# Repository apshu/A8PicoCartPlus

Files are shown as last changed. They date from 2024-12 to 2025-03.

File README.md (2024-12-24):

# A8PicoCart+ (A8PicoCart with autoboot and OLED GFX)

The aim of the A8PicoCart+ is to add autoboot feature to the excellent A8PicoCart. 

The autoboot eliminates the need to navigate trough a complex filesystem or many files (e.g. when playing zaxxon :). On power up it checks if the onboard I²C EERAM stores a valid filename. If the filename is valid, it loads the file automatically before showing the selector interface. If the last file can't be loaded (e.g. deleted) the selector GUI is shown.

If the selector UI is needed, press the Choose button on the cart during powerup.

A simple I²C OLED display is included for fun. The 128×64 monochrome display shows the loaded cart logo if the cartridge is recognized as extended format.

A new PCB was needed for the + functionality. The new PCB is 100% compatible with the original firmware, while utilizing the originally unconnected GP28 & GP29 pins for I²C.

3D printable box with the + features is available.

# A8PicoCart (UnoCart on a Raspberry Pi Pico clone)

The A8PicoCart is a multi-cart for the Atari 8-bit (XL/XE) which you can make at home with only basic soldering skills.
It is based on my earlier UnoCart design but uses a very inexpensive Raspberry Pi Pico clone (£2-3) for an easy build.

When plugged into a PC by USB it becomes a Mass Storage device allowing ROM/CAR/XEX & ATR files to be copied to the cartridge.
When plugged into an Atari these files are shown on the menu and the device will either emulate the selected cartridge type or
act as a XEX file launcher. It also has (very) limited support for ATR files allowing you to do some programming and save your
work to an ATR file.

This page contains everything you need to build the project - firmware to flash to your purple Pico clone, Kicad PCB design files to make a PCB and 3d print files for a nice case. The source code for everything is also here. There is also a manual detailing the full capabilities of the cartridge.

If you build an A8PicoCart consider donating to help fund this and my future projects:



Cased A8PicoCart in a 800xl
A8PicoCart Menu

## Quick Start

Get yourself a purple Raspberry Pi Pico clone (see [this thread](https://forums.raspberrypi.com/viewtopic.php?t=337976) for details) and order a PCB using the KiCad board files provided. You have a choice of two PCB designs - the XE design is for use uncased, with the Pico on the top surface. The XL/XE version is desgined to be mounted in a case (though can be used uncased too) with the Pico on the bottom/back surface. Once you have the Pico clone and PCB, solder the pico as pictured below, depending on your PCB version. Program the firmware onto the device by pressing BOOTSEL on the board and connecting to USB on a PC and drag the firmware (UF2 file) onto the device. It should then remount as A8-PICOCART so you can copy Atari CAR & XEX files to it. Unmount, then plug into your Atari and play! Optionally solder a reset button to reset back to the menu.

**Note**: this project does not work with the official green RPi Pico board. Although the official board has the same
number of physical pins (and will therefore fit in the PCB) - the actual pin functions are different and attempting to use
it may damage the Pico and/or your Atari. The purple clones are cheaper and have a greater number of usuable GPIO pins - 
this is required for the cartridge port emulation to work.

**Warning**: always disconnect from PC/USB before plugging into your Atari or you will damage your Atari and/or PC. This warning mainly
applies to the XE/uncased version of the PCB. The newest version of the XL/XE board makes it physically impossible to connect USB when the
cartridge is inserted in an Atari.

Purple Pico mounted on the PCBs
USB Mass Storage mode

## Inserting the cartridge

Depending on which PCB you choose the Pico clone may be mounted on the front or back of the PCB. When you insert
the cartridge in the Atari make sure the "S..A" side of the cartridge edge (NOT the "1..15" side) is facing upwards (XE) or towards you (XL).

## Purple Pico clones

The firmware is designed for the Purple Pico clones with USB C connector and 16Megs of flash and a single button (BOOTSEL).
I've received these devices with two different types of SPI flash chips - Winbond and (slower) Z-bit. The firmware has been tested with both types.

The project defines a custom board with a higher value for PICO_FLASH_SPI_CLKDIV so it supports the slower Z-bit flash.

Be aware that it's possible you might get one with another type of flash memory chip that has not been tested.

## Reset button

You can solder a push button to the cartridge to get back to the menu and avoid wear on your Atari power switch.
When you reset the cartridge the Atari will crash - just push reset on the Atari itself to get back to the menu.

The button used is a 6x6mm thru-hole tactile momentary switch. If you are going to print a case, then 9mm+ height is suitable.
When you solder the button to the PCB - make sure the lower two holes in the PCB are bridged only when the button is pressed.

It works simply by pulling the RUN pin on the pico clone to ground to reset.

## 3D print files

The STL files can be used to print a 3 part (front, back and logo) cartridge shell. The 2-tone logo is achieved by
changing the filament at the correct z-position when printing a8pico_logo.stl. You'll also need two M3 15mm screws.

Cased A8PicoCart
Cased A8PicoCart

## Changelog

* 7 Oct 2023 - Add new PCB & case design files to make it impossible to insert USB when plugged into Atari. Add support for Microcart (CAR type 52) cartridges. Updated manual.
* 29 Oct 2023 - Adds 3 new cartridge types (thanks to ascrnet)

## Credits

* Design, hardware and firmware by Robin Edwards (electrotrains at atariage)
* XEX loader and OS modifications by Jonathan Halliday (flashjazzcat at atariage)
* Altirra LLE OS used with permision from Avery Lee (phaeron at atariage)

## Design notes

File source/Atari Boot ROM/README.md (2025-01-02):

# How to compile the CART code

* Use MADs assembler [GitHub release page](https://github.com/tebe6502/Mad-Assembler/releases)
* Install Altirra 4.21 or newer [Download Page](https://www.virtualdub.org/altirra.html)
* Use VSCode with [MADS plugin](https://marketplace.visualstudio.com/items?itemName=mirao.mads) and [Atasm Altirra Bridge](https://marketplace.visualstudio.com/items?itemName=cerebus.atasm-altirra-bridge)
* Install [Python](https://www.python.org/) 3.12 or newer

The current setup is available for Windows only. Linux porting should be fairly easy.

Set the Altirra executeable path [-> VSCODE setting](vscode://settings/atasm-altirra-bridge.emulator.altirra.path) to bridge.bat

Add the Altirra bridge specific settings to atasm-build.json
```json
	"_7": "Altirra command line parameters for developing a cartridge",
	"bridgeParams": {
		"altirraExecutable": "D:\\Games\\Altirra\\Altirra64.exe",
		"bptList": ["A001","read_joystick.done"],
		"altirraDebugArgumentTemplate": "/cartmapper 1 /cart {' '.join(args[1:])} /debugcmd:\\\".sourcemode on\\\" {' '.join(map('/debugcmd:\"bp {}\"'.format, getattr(config.bridgeParams, 'bptList', [])))}",
		"altirraArgumentTemplate": "/cartmapper 1 /cart {' '.join(args[1:])}"
	}
```
> [!IMPORTANT]
> Adjust the "_altirraExecutable_" to match the full path and executeable of your selected Altirra

> [!NOTE]
> The example above is for developing cartridges

> [!TIP]
> "_bptList_" section may contain Address or symbol name to set breakpoints on load.

# Convert the compiled code to _.h_

When the Cart code is finished, run the _convert.bat_, review the generated _rom.h_ and copy the _rom.h_ to the Pico source folder. 

Recompile the Pico Code and the new CART is incorporated as default.

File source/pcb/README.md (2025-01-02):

# XL/XE version PCB (which fits the 3d printed case design)

* KiCad Project wirh 3D models 
* KiCad Version: 8.0.3, release build
* A zip file of the gerbers (JLCPCB specification).
* Updated version with EERAM and OLED display 
 
## PCB specifications:
* 70.04 × 53.8 mm
* 2 layers
* 1.6 mm thickness
* Minimum drill 0.3 mm
* Hard gold fingers with bevelled edge will make your PCB last longer, but at a much higher cost.

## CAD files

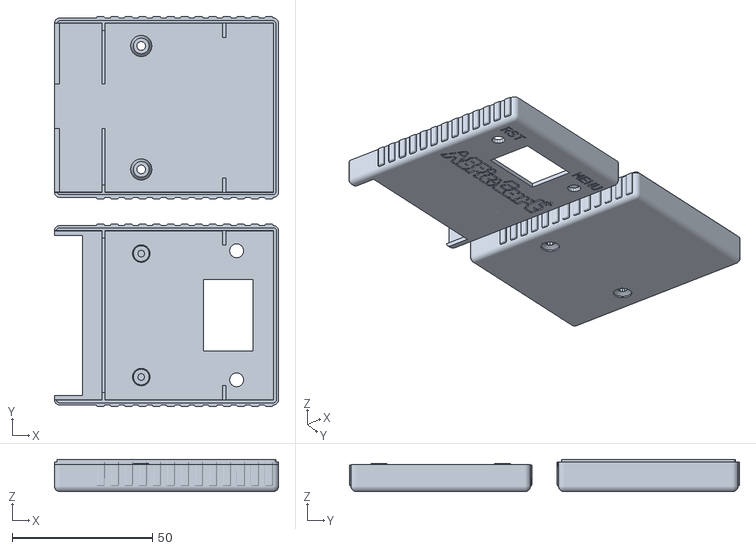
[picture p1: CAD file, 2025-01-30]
release/a8picoplus_shell.stl
80.0 x 139.0 x 11.5

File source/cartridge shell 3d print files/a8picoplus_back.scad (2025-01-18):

/* A8PicoCart shell
   (c) R.Edwards 2023
*/

include <a8picoplus_dimensions.scad>
use <cube_round.scad>

module back_outside()
{
    cube_round([cart_length, cart_width, cartb_height-rim_height], corner_r,
        fn=corner_fn, round_top=false);

    // rim
    translate([sides_thickness/2+rim_clearance, sides_thickness/2+rim_clearance, 0])
        cube_round([cart_length-sides_thickness-2*rim_clearance, cart_width-
            2*sides_thickness/2 - 2*rim_clearance,
            cartb_height], corner_r-sides_thickness/2,
            fn=corner_fn, round_top=false);

    // ridges
    for (i = [15: 5: cart_length-5])
        translate([i, -ridge_width, corner_r])
            cube_round([3, cart_width + 2*ridge_width,
                cartb_height-rim_height-corner_r],r=ridge_width,fn=corner_fn,round_top=false);

}


module back_inside()
{
    //FIXME  name the "4"
    // upper part, whole lenght
    translate([-1, sides_thickness, front_thickness+4])
        cube_round([cart_length-sides_thickness+1,
            cart_width-sides_thickness*2,
            cartb_height-front_thickness],
            r = corner_r-sides_thickness, fn = corner_fn,
            round_top=false);

    //inside part without the wall on the header end
    translate([sides_thickness, sides_thickness, front_thickness])
        cube_round([cart_length-sides_thickness*2,
            cart_width-sides_thickness*2,
            cartb_height-front_thickness],
            r = corner_r-sides_thickness, fn = corner_fn,
            round_top=false);
    // cutout USB slot
    translate([-1, (cart_width-16)/2+0.5, front_thickness])    // pico is 0.5 mm off center
        cube([40+1, 16, cartb_height]);


}

module screw_hole()
{
    translate([0, 0, -1])
        cylinder(h = supportb_height - 1.2 + 2, r = 1.6,  $fs = 1);
    translate([0, 0, -1])
        cylinder(h = 1.6, r = 3.5, $fs = 1);
    translate([0, 0, 0.6])
        cylinder(h = front_thickness-0.6, r1 = 3.5, r2 = 1.8,  $fs = 1);
}

module pcb_support()
{
        difference() {
            translate([17, sides_thickness, sides_thickness/2])
                cube([support_thickness, cart_width-sides_thickness*2,
cartb_height-sides_thickness/2]);
            translate([17-1, (cart_width-55)/2, supportb_height])
                cube([support_thickness+2, 55, cartb_height-supportb_height+1]);

               // cutout USB slot
            translate([17-1, (cart_width-16)/2+0.5, front_thickness])    // pico is 0.5 mm off center
                 cube([support_thickness+2, 16, cartb_height]);
        }

        translate([60, sides_thickness, sides_thickness])
            cube([support_thickness, 7-sides_thickness,
                    supportb_height-sides_thickness]);
        translate([60, cart_width-7, sides_thickness])
            cube([support_thickness, 7-sides_thickness/2,
supportb_height-sides_thickness]);



}

module back() {

difference() {
    union() {
        difference() {
            // main shell
            back_outside();
                        // make hollow
            back_inside();
       } 
   
        // pcb supports
        pcb_support();

        // screw stud
        translate([31, (cart_width-screw_sep)/2, 0])
                cylinder(h = supportb_height - 1.2, r1 = 4, r2 = 2.8,  $fs = 1);
        translate([31, cart_width-(cart_width-screw_sep)/2, 0])
                cylinder(h = supportb_height - 1.2, r1 = 4, r2 = 2.8,  $fs = 1);
    }


    // screw holes
    translate([31, (cart_width-screw_sep)/2, 0])
        screw_hole();

    translate([31, cart_width-(cart_width-screw_sep)/2, 0])
        screw_hole();

}

}


back();

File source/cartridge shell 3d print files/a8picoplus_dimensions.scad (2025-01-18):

/* A8PicoCart shell
   (c) R.Edwards 2023
*/

/*common ones */
/* Dimensions */
ridge_width = 0.5;
cart_length=80;
cart_width=65 - (ridge_width*2);
screw_sep = 44;
front_thickness = 1.6;
sides_thickness = 1.8;
support_thickness = 1.2 - 0.05;
rim_height=1;
rim_clearance=0.1;

corner_r=2;
corner_fn=32;

/* back */
/* height of the back side part */
cartb_height=11.5;
supportb_height = 10.5;

/* front */

/* Features */
menu_button = true;
OLED_mount = true;
show_logo = true;

/*height of the front side part */
cartf_height=9.6;
supportf_height = 7.6;
port_cut_height=10;
logo_width = 14.5;
logo_height = 58;
logo_image = "a8picoplus_logo.png";
image_size=[363,88];

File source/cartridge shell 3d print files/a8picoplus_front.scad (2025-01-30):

/* A8PicoCart shell
   (c) R.Edwards 2023
   A8PicCart+ shell
   APShu 2025
*/

include <a8picoplus_dimensions.scad>
include <cube_round.scad>

module front_outside()
{
    // main shell
    cube_round([cart_length, cart_width, cartf_height],r=corner_r,fn=corner_fn, round_top=false);

    // ridges
    for (i = [15: 5: cart_length-5])
                translate([i, -ridge_width, corner_r])
                    cube_round([3, cart_width + 2*ridge_width,
cartb_height-rim_height-1-corner_r],r=ridge_width,round_top=false);


}

module front_inside() {
    // rims
    translate([sides_thickness/2-rim_clearance,cart_width -
        sides_thickness/2+rim_clearance, cartf_height-rim_height +
        rim_height+corner_r])
        rotate([180,0,0])
        cube_round([cart_length-sides_thickness+2*rim_clearance,
            cart_width-sides_thickness+2*rim_clearance,
            rim_height+corner_r],
            r=corner_r-sides_thickness/2,fn=corner_fn,round_top=false);

    // make hollow
    translate([-1, sides_thickness, front_thickness])
        cube_round([cart_length-sides_thickness+1,
            cart_width-sides_thickness*2,
            cartf_height-front_thickness+1],
            r=corner_r-sides_thickness,fn=corner_fn,round_top=false);

    // cutout cart port
    translate([-1, (cart_width-57)/2, -1])
        cube([port_cut_height+1, 57, cartf_height+2]);

    // Reset button
    translate([cart_length-15, 9, -1])
        cylinder(h = front_thickness+2, r1 = 2.5, r2 = 2.5,  $fs = 1); 

    // Menu button
    if (menu_button) {
        translate([cart_length-15, cart_width-9, -1])
            cylinder(h = front_thickness+2, r1 = 2.5, r2 = 2.5,  $fs = 1); 
    }
    
    // OLED mount
    if (OLED_mount) {
        translate([cart_length-18, cart_width/2, 0])
            cube([17.6, 25.6,front_thickness*4], center=true); 
    }
}

module front_screw_mount()
{
    difference() {
        cylinder(h = supportf_height + 2.5, r1 = 3.2, r2 = 2.8,  $fs = 1);
        translate([0,0,-1])
            cylinder(h = supportf_height + 2.5+2, r1 = 1.25, r2 = 1.25,  $fs = 1);
    }

}

module front_wo_logo()
{
    difference() {
        front_outside();
        front_inside();
    }    
    // pcb supports
    difference() {
        //FIXME 17 as variable
        translate([17, sides_thickness/2, sides_thickness/2])
            cube([support_thickness, cart_width-sides_thickness,
cartf_height-rim_height-sides_thickness/2]);
        translate([17-1, (cart_width-55)/2, supportf_height])
            cube([support_thickness+2, 55, cartf_height-supportf_height]);
    }

    translate([60, sides_thickness/2, sides_thickness/2])
        cube([support_thickness, 7-sides_thickness/2,
supportf_height-sides_thickness/2]);
    translate([60, cart_width-7, sides_thickness/2])
        cube([support_thickness, 7-sides_thickness/2,
supportf_height-sides_thickness/2]);

    // screw holes
    translate([31, (cart_width-screw_sep)/2, 0])
        front_screw_mount();
    translate([31, cart_width-(cart_width-screw_sep)/2, 0])
        front_screw_mount();
}

module front_logo_hole() {

    difference() {
        front_wo_logo();
        // logo space
        translate([cart_length-logo_height-2, cart_width-logo_width-3.5, -1])
            cube([logo_height, logo_width, 1+1]);
    }
}

module logo()
{
    echo("rendering logo");
    rect_line_width=0.5;
    logo_depth=0.6;
    scl = (logo_height-rect_line_width)/image_size[0];

    /* logo text */
    intersection(){
        cube([logo_height, logo_width, logo_depth+1]);
    //FIXME why the "-1" to shift the logo lower and to the left side??
        translate([logo_height/2+rect_line_width-0.5,logo_width/2+rect_line_width -1 ,100/2])
            scale([scl,scl,1])
            mirror([0,1,0])
            surface(file = logo_image, center = true, invert = true);
    }
}

module reset_label()
{
    font = "Liberation Mono:style=Medium";
    rpi_logo_scale = 0.22;
    rst_height = 1.6;

    rotate([0,0,90])
        mirror([0,1,0])
            linear_extrude(height = rst_height) {
                translate([-38,0]) 
                    text(text = str("RST"), font = font, size = 30);
            }
}

module menu_label()
{
    font = "Liberation Mono:style=Medium";
    rpi_logo_scale = 0.22;
    rst_height = 1.6;

    rotate([0,0,90])
        mirror([0,1,0])
            linear_extrude(height = rst_height) {
                translate([-55,0]) 
                    text(text = str("MENU"), font = font, size = 30);
            }
}

module front() {

    difference() {
        front_wo_logo();
        //logo rectangle
        if (show_logo) {
            if (OLED_mount) {
                translate([cart_length-28,(cart_width-logo_height)/ 2, -1]) rotate([0, 0, 90]) logo();
            } else {
                translate([cart_length-logo_height-3, (cart_width-logo_width)/ 2, -1]) logo();
            }
        }
        translate([cart_length-15+5, 9, -1]) scale([0.15,0.15,1]) reset_label();
        if (menu_button) {
            translate([cart_length-15+5, cart_width-9, -1]) scale([0.15,0.15,1]) menu_label();
        }
    }
}

front();

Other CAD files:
source/cartridge shell 3d print files/a8picoplus_shell.scad
source/cartridge shell 3d print files/cube_round.scad

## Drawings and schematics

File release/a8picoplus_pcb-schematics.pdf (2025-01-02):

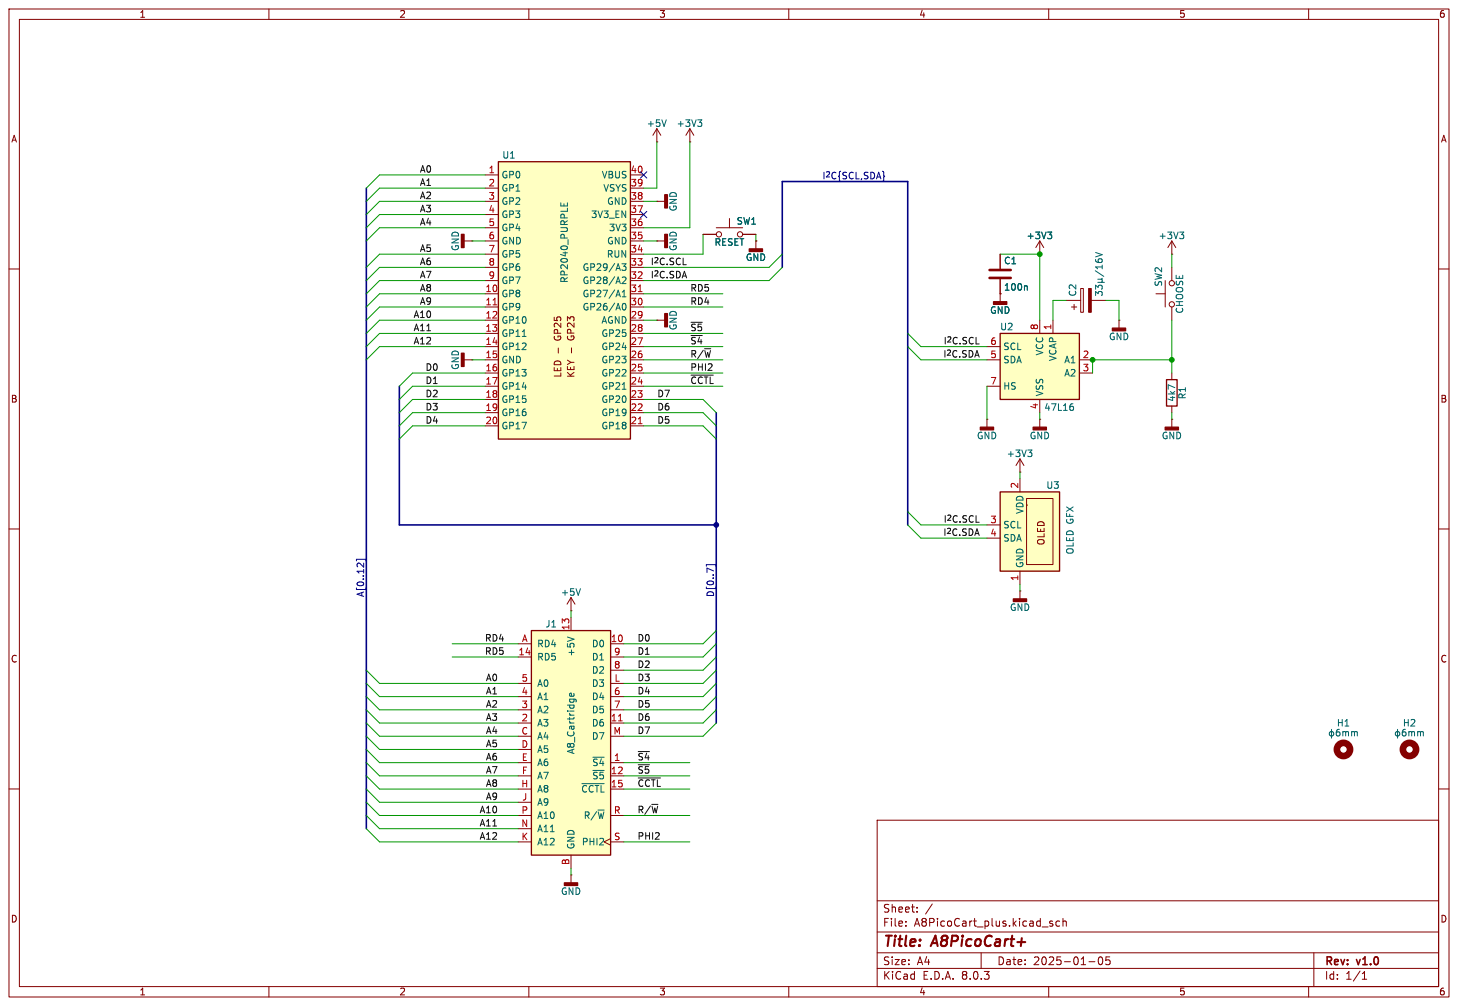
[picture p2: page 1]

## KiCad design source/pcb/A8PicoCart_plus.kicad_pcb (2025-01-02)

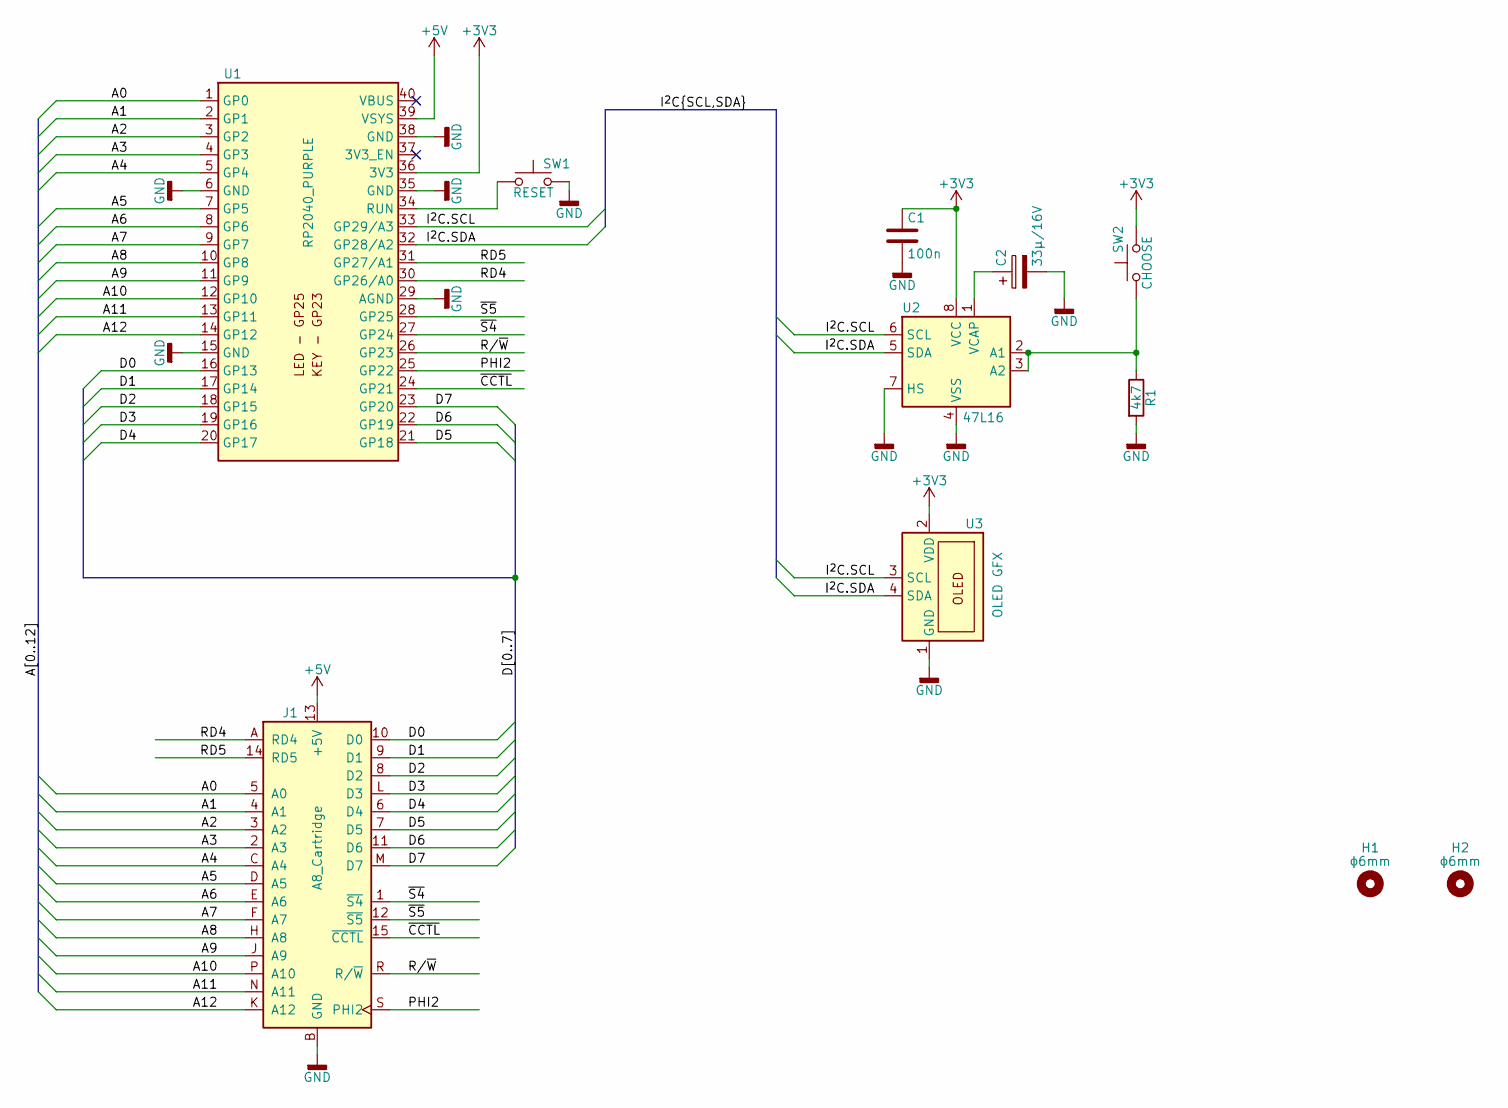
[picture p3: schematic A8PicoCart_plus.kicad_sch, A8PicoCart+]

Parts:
C1: 100n; C_0805_2012Metric_Pad1.18x1.45mm_HandSolder
C2: 33µ/16V; CP_Radial_D4.0mm_P2.00mm
H1, H2: ϕ6mm; MountingHole_6mm
J1: A8_Cartridge; Cartridge_A8
R1: 4k7; R_0805_2012Metric_Pad1.20x1.40mm_HandSolder
SW1: RESET; SW_PUSH_6mm_H8mm
SW2: CHOOSE; SW_PUSH_6mm_H8mm
U1: RP2040_PURPLE; RP2040_purple_nodbg
U2: 47L16; SOIC-8_3.9x4.9mm_P1.27mm
U3: OLED GFX; JST_XH_B4B-XH-A_1x04_P2.50mm_Vertical

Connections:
+3V3: C1.1, SW2.2, U1.36 (3V3), U2.8 (VCC), U3.2 (VDD)
+5V: J1.13 (+5V), U1.39 (VSYS)
/A0: J1.5 (A0), U1.1 (GP0)
/A1: J1.4 (A1), U1.2 (GP1)
/A2: J1.3 (A2), U1.3 (GP2)
/A3: J1.2 (A3), U1.4 (GP3)
/A4: J1.C (A4), U1.5 (GP4)
/A5: J1.D (A5), U1.7 (GP5)
/A6: J1.E (A6), U1.8 (GP6)
/A7: J1.F (A7), U1.9 (GP7)
/A8: J1.H (A8), U1.10 (GP8)
/A9: J1.J (A9), U1.11 (GP9)
/A10: J1.P (A10), U1.12 (GP10)
/A11: J1.N (A11), U1.13 (GP11)
/A12: J1.K (A12), U1.14 (GP12)
/D0: J1.10 (D0), U1.16 (GP13)
/D1: J1.9 (D1), U1.17 (GP14)
/D2: J1.8 (D2), U1.18 (GP15)
/D3: J1.L (D3), U1.19 (GP16)
/D4: J1.6 (D4), U1.20 (GP17)
/D5: J1.7 (D5), U1.21 (GP18)
/D6: J1.11 (D6), U1.22 (GP19)
/D7: J1.M (D7), U1.23 (GP20)
/I^{2}C.SCL: U1.33 (GP29/A3), U2.6 (SCL), U3.3 (SCL)
/I^{2}C.SDA: U1.32 (GP28/A2), U2.5 (SDA), U3.4 (SDA)
/PHI2: J1.S (PHI2), U1.25 (GP22)
/RD4: J1.A (RD4), U1.30 (GP26/A0)
/RD5: J1.14 (RD5), U1.31 (GP27/A1)
/R/~W: J1.R (R/~W), U1.26 (GP23)
/~CCTL: J1.15 (~CCTL), U1.24 (GP21)
/~S4: J1.1 (~S4), U1.27 (GP24)
/~S5: J1.12 (~S5), U1.28 (GP25)
GND: C1.2, C2.2, J1.B (GND), R1.2, SW1.2, U1.6 (GND), U1.15 (GND), U1.29 (AGND), U1.35 (GND), U1.38 (GND), U2.4 (VSS), U2.7 (HS), U3.1 (GND)
unnamed: SW1.1, U1.34 (RUN)
unnamed: R1.1, SW2.1, U2.2 (A1), U2.3 (A2)
unnamed: C2.1, U2.1 (VCAP)

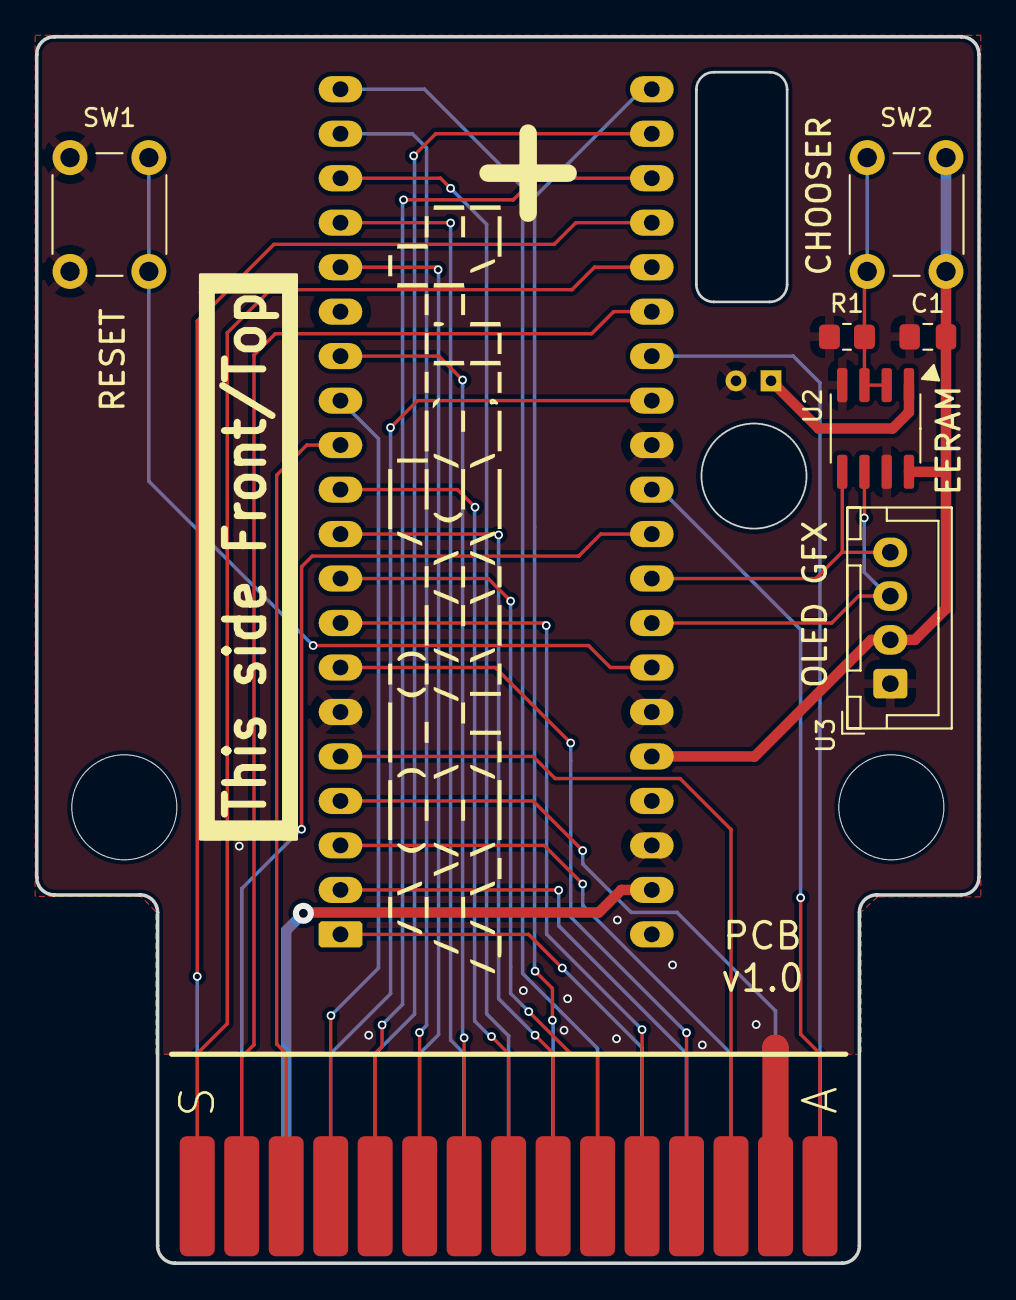
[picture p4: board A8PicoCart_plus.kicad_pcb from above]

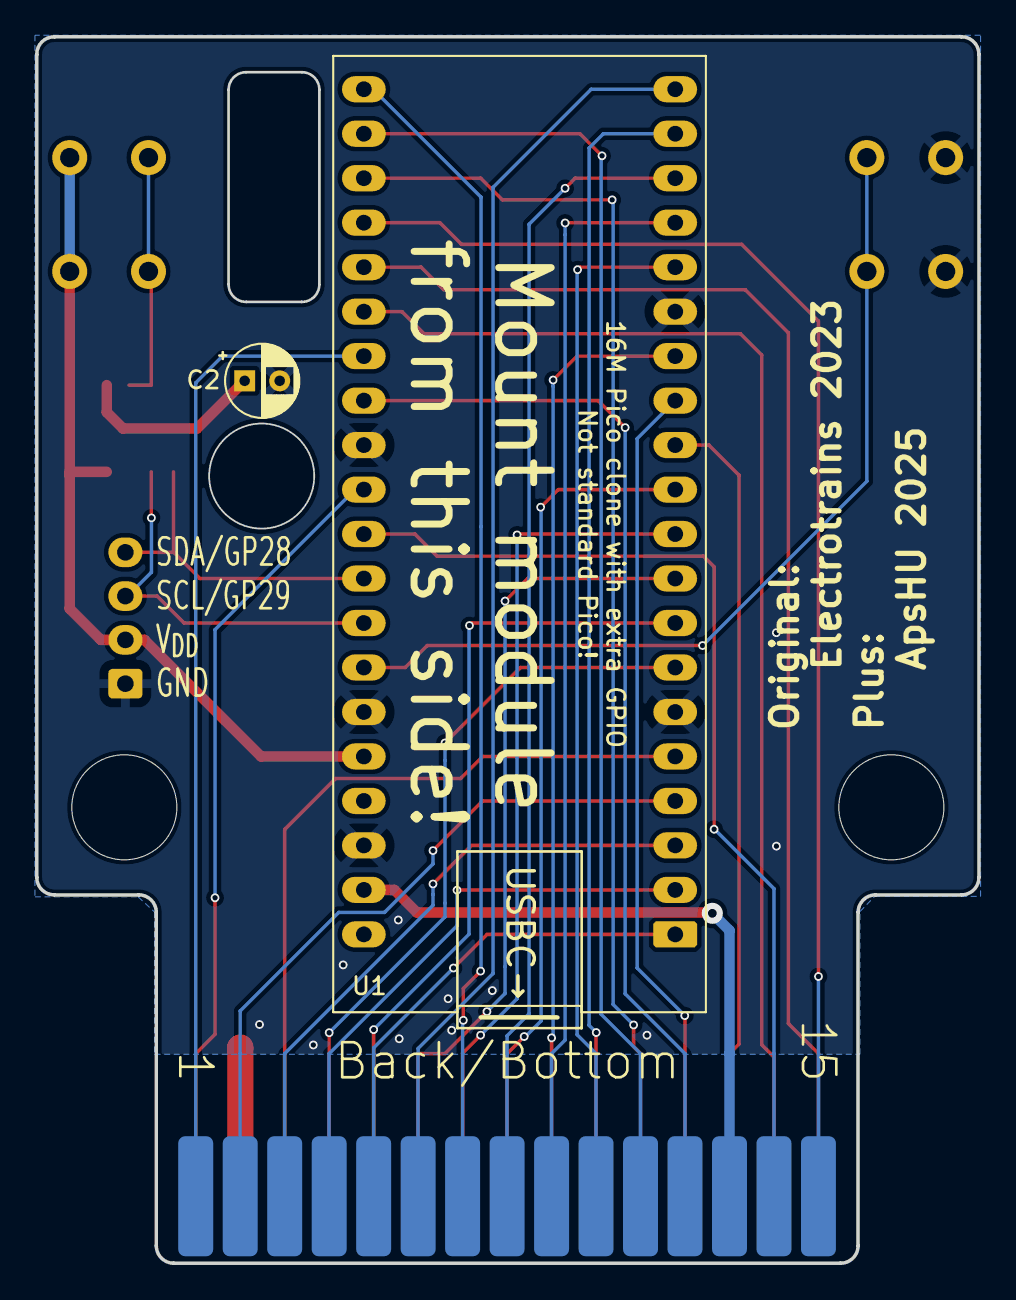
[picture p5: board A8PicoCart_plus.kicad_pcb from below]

Board: 2 copper layers, 53.8 x 70.0 mm, 11 parts (3 on the bottom side), 36 nets.

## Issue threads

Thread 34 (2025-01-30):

Case OLED cutout too small

apshu, 2025-01-30:
Make 1mm larger

Closed 2025-01-30.

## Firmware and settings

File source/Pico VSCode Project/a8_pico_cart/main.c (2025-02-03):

/**
 *    _   ___ ___ _       ___          _   
 *   /_\ ( _ ) _ (_)__ _ / __|__ _ _ _| |_ 
 *  / _ \/ _ \  _/ / _/_\ (__/ _` | '_|  _|
 * /_/ \_\___/_| |_\__\_/\___\__,_|_|  \__|
 *                                         
 * 
 * Atari 8-bit cartridge for Raspberry Pi Pico (16MB clone with all GPIO)
 *
 * Robin Edwards 2023
 *
 * Needs to be a release NOT debug build for the cartridge emulation to work
 * 
 * Edit myboard.h depending on the type of flash memory on the pico clone
 */

#include <stdlib.h>
#include <stdio.h>
#include <string.h>

#include "pico/stdlib.h"
#include "pico/time.h"
#include "tusb.h"

#include "atari_cart.h"
#include "fatfs_disk.h"

#include "hardware/i2c.h"
#include "ssd1306.h"

void cdc_task(void);

int main(void)
{
    // check to see if we are plugged into Atari 8-bit
    // by checking for high on PHI2 gpio for 100ms
    gpio_init(ATARI_PHI2_PIN);
    gpio_set_dir(ATARI_PHI2_PIN, GPIO_IN);

    // Configuring the I2C host mode
    i2c_init(i2c_default, DEFAULT_I2C_CLK_SPEED);
    gpio_set_function(PICO_DEFAULT_I2C_SCL_PIN, GPIO_FUNC_I2C);
    gpio_set_function(PICO_DEFAULT_I2C_SDA_PIN, GPIO_FUNC_I2C);
    gpio_pull_up(PICO_DEFAULT_I2C_SCL_PIN);
    gpio_pull_up(PICO_DEFAULT_I2C_SDA_PIN);

    while (to_ms_since_boot(get_absolute_time()) < 100)
    {
      if (gpio_get(ATARI_PHI2_PIN))
        atari_cart_main();
    }

  // we are presumably powered from USB
  // enter USB mass storage mode

  stdio_init_all();   // for serial output, via printf()
  printf("Start up\n");  
  
  if (SSD1306_init()) {     // Init GFX display
    // Initialize render area for entire frame (SSD1306_WIDTH pixels by SSD1306_NUM_PAGES pages)
    uint8_t lcd_buf[SSD1306_BUF_LEN];
    // zero the entire display buffer
    memset(lcd_buf, 0, SSD1306_BUF_LEN);
    GFX_render_area_t frame_area = {
      start_col: 0,
      end_col : SSD1306_WIDTH - 1,
      start_page : 0,
      end_page : SSD1306_NUM_PAGES - 1
    };

    GFX_calc_render_area_buflen(&frame_area);
    // Render the text
    GFX_WriteString(lcd_buf, 15, (SSD1306_HEIGHT>>1) - 10, "Drag and drop");
    GFX_WriteString(lcd_buf, 20, (SSD1306_HEIGHT>>1) + 10, "Atari files");
    // Show the buffer on screen
    SSD1306_render(lcd_buf, &frame_area);
  }
  
  // init device stack on configured roothub port
  tud_init(BOARD_TUD_RHPORT);

  while (1)
  {
    tud_task(); // tinyusb device task

    cdc_task();
  }

  return 0;
}

//--------------------------------------------------------------------+
// Device callbacks
//--------------------------------------------------------------------+

// Invoked when device is mounted
void tud_mount_cb(void)
{
  printf("Device mounted\n"); 
  if (!mount_fatfs_disk()) {
    // Issues with FS, complete FS format
    create_fatfs_disk();
    // Reset EERAM regardless of NOAUTOBOOT button
    reset_eeram(true); 
  }
}

// Invoked when device is unmounted
void tud_umount_cb(void)
{
  printf("Device unmounted\n");  
}

// Invoked when usb bus is suspended
// remote_wakeup_en : if host allow us  to perform remote wakeup
// Within 7ms, device must draw an average of current less than 2.5 mA from bus
void tud_suspend_cb(bool remote_wakeup_en)
{
  (void) remote_wakeup_en;
//  blink_interval_ms = BLINK_SUSPENDED;
}

// Invoked when usb bus is resumed
void tud_resume_cb(void)
{
//  blink_interval_ms = BLINK_MOUNTED;
}


//--------------------------------------------------------------------+
// USB CDC
//--------------------------------------------------------------------+
void cdc_task(void)
{
  // connected() check for DTR bit
  // Most but not all terminal client set this when making connection
  // if ( tud_cdc_connected() )
  {
    // connected and there are data available
    if ( tud_cdc_available() )
    {
      // read data
      char buf[64];
      uint32_t count = tud_cdc_read(buf, sizeof(buf));
      (void) count;

      // Echo back
      // Note: Skip echo by commenting out write() and write_flush()
      // for throughput test e.g
      //    $ dd if=/dev/zero of=/dev/ttyACM0 count=10000
      tud_cdc_write(buf, count);
      tud_cdc_write_flush();
    }
  }
}

// Invoked when cdc when line state changed e.g connected/disconnected
void tud_cdc_line_state_cb(uint8_t itf, bool dtr, bool rts)
{
  (void) itf;
  (void) rts;

  // TODO set some indicator
  if ( dtr )
  {
    // Terminal connected
  }else
  {
    // Terminal disconnected
  }
}

// Invoked when CDC interface received data from host
void tud_cdc_rx_cb(uint8_t itf)
{
  (void) itf;
}

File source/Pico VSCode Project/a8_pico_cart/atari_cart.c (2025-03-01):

/**
 *    _   ___ ___ _       ___          _   
 *   /_\ ( _ ) _ (_)__ _ / __|__ _ _ _| |_ 
 *  / _ \/ _ \  _/ / _/_\ (__/ _` | '_|  _|
 * /_/ \_\___/_| |_\__\_/\___\__,_|_|  \__|
 *                                         
 * 
 * Atari 8-bit cartridge for Raspberry Pi Pico
 *
 * Robin Edwards 2023
 *
 * Needs to be a release NOT debug build for the cartridge emulation to work
 * 
 * Changes from UnoCart:
 * - Attempts to get S4/S5, RD4/RD5 MMU behaviour correct on 400/800
 *   https://forums.atariage.com/topic/241888-ultimate-cart-sd-multicart-technical-thread/page/10/#comment-4266797
 * - Adds 4k carts (CAR type 58)
 * - Adds Turbsoft carts (CAR types 50,51)
 * - Adds ATRAX 128k carts (CAR type 17)
 * - Adds Microcalc/Utracart (CAR type 52)
 * - Adds Standard 2k cars (CAR type 57)
 * - Adds Phoenix 8k cars (CAR type 39)
 * - Adds Blizzard 4k cars (CAR type 46)
 * - Adds Dawliah 32k cars (CAR type 69)
 * - Adds Telelink II 8k car (CAR type 78)
 * - Adds Turbo 2000 8k cars (CAR type 253 exclusive emulation)
 * - Adds JNSoft 16k cars (CAR type 252 exclusive emulation)
 */

#include <string.h>
#include <stdlib.h>

#include "pico/stdlib.h"
#include "hardware/sync.h"
#include "hardware/clocks.h"
#include "hardware/i2c.h"

#include "atari_cart.h"

#include "ff.h"
#include "fatfs_disk.h"

#include "eeram_i2c.h"
#include "ssd1306.h"

#if !(defined(PICO_DEFAULT_I2C_SCL_PIN) && defined (PICO_DEFAULT_I2C_SDA_PIN) && defined(DEFAULT_I2C_CLK_SPEED))
#error "I2C not defined"
#endif

#define ALL_GPIO_MASK   	0x3FFFFFFF & ~((1 << PICO_DEFAULT_I2C_SCL_PIN) | (1 << PICO_DEFAULT_I2C_SDA_PIN))
#define ADDR_GPIO_MASK  	0x00001FFF
#define DATA_GPIO_MASK  	0x001FE000
#define CCTL_GPIO_MASK  	0x00200000  // gpio 21
#define PHI2_GPIO_MASK  	(1 << ATARI_PHI2_PIN)  // gpio 22
#define RW_GPIO_MASK    	0x00800000  // gpio 23
#define S4_GPIO_MASK    	0x01000000  // gpio 24
#define S5_GPIO_MASK    	0x02000000  // gpio 25

#define S4_S5_GPIO_MASK 	0x03000000
#define CCTL_RW_GPIO_MASK 	0x00A00000

#define RD4_PIN         26
#define RD5_PIN         27

#define RD4_LOW             gpio_put(RD4_PIN, 0)
#define RD4_HIGH            gpio_put(RD4_PIN, 1)
#define RD5_LOW             gpio_put(RD5_PIN, 0)
#define RD5_HIGH            gpio_put(RD5_PIN, 1)
#define SET_DATA_MODE_OUT   gpio_set_dir_out_masked(DATA_GPIO_MASK)
#define SET_DATA_MODE_IN    gpio_set_dir_in_masked(DATA_GPIO_MASK)

#include "rom.h"
#include "osrom.h"

unsigned char cart_ram[128*1024];
unsigned char cart_d5xx[256] = {0};
char errorBuf[40];

#define CART_CMD_OPEN_ITEM			0x00
#define CART_CMD_READ_CUR_DIR		0x01
#define CART_CMD_GET_DIR_ENTRY		0x02
#define CART_CMD_UP_DIR				0x03
#define CART_CMD_ROOT_DIR			0x04
#define CART_CMD_SEARCH				0x05
#define CART_CMD_GET_AUTOBOOT_INFO	0x06
#define CART_CMD_LOAD_SOFT_OS		0x10
#define CART_CMD_SOFT_OS_CHUNK		0x11
#define CART_CMD_MOUNT_ATR			0x20	// unused, done automatically by firmware
#define CART_CMD_READ_ATR_SECTOR	0x21
#define CART_CMD_WRITE_ATR_SECTOR	0x22
#define CART_CMD_ATR_HEADER			0x23
#define CART_CMD_RESET_FLASH		0xF0
#define CART_CMD_NO_CART			0xFE
#define CART_CMD_ACTIVATE_CART  	0xFF

#define CART_TYPE_NONE				0
#define CART_TYPE_8K				1	// 8k
#define CART_TYPE_16K				2	// 16k
#define CART_TYPE_XEGS_32K			3	// 32k
#define CART_TYPE_XEGS_64K			4	// 64k
#define CART_TYPE_XEGS_128K			5	// 128k
#define CART_TYPE_SW_XEGS_32K		6	// 32k
#define CART_TYPE_SW_XEGS_64K		7	// 64k
#define CART_TYPE_SW_XEGS_128K		8	// 128k
#define CART_TYPE_MEGACART_16K		9	// 16k
#define CART_TYPE_MEGACART_32K		10	// 32k
#define CART_TYPE_MEGACART_64K		11	// 64k
#define CART_TYPE_MEGACART_128K		12	// 128k
#define CART_TYPE_BOUNTY_BOB		13	// 40k
#define CART_TYPE_ATARIMAX_1MBIT	14	// 128k
#define CART_TYPE_WILLIAMS_64K		15	// 32k/64k
#define CART_TYPE_OSS_16K_TYPE_B	16	// 16k
#define CART_TYPE_OSS_8K			17	// 8k
#define CART_TYPE_OSS_16K_034M		18	// 16k
#define CART_TYPE_OSS_16K_043M		19	// 16k
#define CART_TYPE_SIC_128K			20	// 128k
#define CART_TYPE_SDX_64K			21	// 64k
#define CART_TYPE_SDX_128K			22	// 128k
#define CART_TYPE_DIAMOND_64K		23	// 64k
#define CART_TYPE_EXPRESS_64K		24	// 64k
#define CART_TYPE_BLIZZARD_16K		25	// 16k
#define CART_TYPE_4K				26	// 4k
#define CART_TYPE_TURBOSOFT_64K		27	// 64k
#define CART_TYPE_TURBOSOFT_128K	28	// 128k
#define CART_TYPE_ATRAX_128K		29	// 128k
#define CART_TYPE_MICROCALC			30	// 32k
#define CART_TYPE_2K				31  // 2k
#define CART_TYPE_PHOENIX_8K		32	// 8k
#define CART_TYPE_BLIZZARD_4K		33	// 4k
#define CART_TYPE_ADAWLIAH_32k		34	// 32K
#define CART_TYPE_TELELINK2_8k		35	// 8k
#define CART_TYPE_JNSOFT_16k		252	// 16K
#define CART_TYPE_T2000_8K			253 // 8k
#define CART_TYPE_ATR				254
#define CART_TYPE_XEX				255

typedef struct {
	char isDir;
	char filename[13];
	char long_filename[32];
	char full_path[210];
} DIR_ENTRY;	// 256 bytes = 256 entries in 64k

#define EERAM_DATA_VALID_MAGIC_PATTERN 	(0x5A)
#define EERAM_AUTOBOOT_DATA_ADDRESS		(0x00)

typedef struct  __attribute__((packed)) {
	uint8_t dataValidMagic; // valid if == EERAM_DATA_VALID_MAGIC_PATTERN
	uint8_t fullPathChecksum; // 2's complement sum of all bytes of full_path(CSUM+sum(autobootFilePath) == 0)
	struct {
		char filename[sizeof(((DIR_ENTRY*)0)->filename)];
		char full_path[sizeof(((DIR_ENTRY*)0)->full_path)]; // isDir must be false. full_path must be longer than 0
	} autobootFilePath;
} EERAM_storage_t;

EERAM_storage_t eeramDataBuf;
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

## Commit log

2024-06-30 Update atari_cart.c
    special case for williams 64K cartridges that are marked 32K
2024-10-04 Joy 2B+ support and fix loader xex
    [A8PicoCart.asm]
2024-12-24 Pi Pico VS Code Extension add to CMAKE
2024-12-24 PHI2 pin configuration consistency
2024-12-24 I2C import sanity check
2024-12-24 I2C pins are not reconfigured as GPIO
2024-12-24 I2C initalization
2024-12-24 Add SSD1309 I²C driver Fixes apshu/A8PicoCartPlus#5
2024-12-24 Including SSD1306 I²C driver to CMakeLists
2024-12-25 Refactored driver API
2024-12-25 Driver routines in .h
2024-12-25 Changed board type to the actual board on PCB
2024-12-25 Due to Pico type change, memory size redefinition not required
2024-12-28 Old PCB files are not needed, A8PicoCartPlus PCB is 100% compatible with the old FW
    [A8PicoCart.kicad_pcb, A8PicoCart.kicad_sch]
2024-12-28 A8 PicoCart+ PCB, schematics,3D models and manufacturing files Closes apshu/A8PicoCartPlus#9
    [A8PicoCart_plus.kicad_pcb, A8PicoCart_plus.kicad_sch]
2025-01-02 menu text modified Fixes apshu/A8PicoCartPlus#19
    [A8PicoCart.asm]
2025-01-02 Binary file changed and rom.h modified in the PICO code Closes apshu/A8PicoCartPlus#19
2025-01-04 Add 47L16 EERAM driver Closes apshu/A8PicoCartPlus#6
2025-01-04 Anonymous label for skipping the reset FLASH routine
    [A8PicoCart.asm]
2025-01-05 Rom code with "skip AB" on pico
    [atari_cart.c]
2025-01-05 EERAM is reset when filesystem is reset
    [atari_cart.c, main.c]
2025-01-05 Revert "EERAM boot only if no fs based autoboot"
    This reverts commit 280ecc6d0caf5f8ac136993d2f14786536b5573b.
    [atari_cart.c]
2025-01-05 fs_based autoboot from "AUTOBOOT" file. Empty file skips autoboot process
    [atari_cart.c]
2025-01-06 Skip FS and EERAM based autoboot if NOAUTOBOOT button pressed
    [atari_cart.c]
2025-01-18 Improved comment
    [a8pico_front.scad]
2025-01-18 Optional OLED window and menu button
    [a8pico_front.scad]
2025-01-18 Adjusted positions and removed frame from +logo
    [a8pico_front.scad]
2025-01-18 Eliminate old versions
    [a8pico_back.scad, a8pico_back.stl]
2025-01-18 Eliminate debug message
    [cube_round.scad]
2025-01-18 Constants from common file, no logo only
    [a8pico.scad]
2025-01-18 Improved comments
    [a8pico_dimensions.scad]
2025-01-18 OLED, menu and more constants to common include
    [a8pico_dimensions.scad, a8pico_front.scad]
2025-01-18 Remove old files
    [a8pico_logo.stl]
2025-01-18 Renamed generator files, removed generatums
    [a8pico.scad, a8pico_back_v2.scad, a8pico_back_v2.stl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]
2025-01-18 Moved 3D shell generator sources to source folder
    [a8picoplus_back.scad, a8picoplus_dimensions.scad, a8picoplus_front.scad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]
2025-01-18 Shell for 3D printing Closes A8PicoCartPlus OLED modified casing apshu/A8PicoCartPlus#10
    [a8picoplus_shell.stl]
2025-01-18 PCB separated to release and sources
    [A8PicoCart_plus.kicad_pcb, A8PicoCart_plus.kicad_sch]
2025-01-30 Update a8picoplus_front.scad
    Window for OLED made bigger
    [a8picoplus_front.scad]
2025-01-30 Case OLED cutout 25.6x17.6mm Fixes apshu/A8PicoCartPlus#34
    [a8picoplus_shell.stl]
2025-02-03 Removed double allocated OLED frame buffer Fixes apshu/A8PicoCartPlus#8
    [main.c]
2025-02-03 LCD format loader and display framebuffer
2025-03-01 Erase LCD screen on reset Fixes apshu/A8PicoCartPlus#38
    [atari_cart.c]
